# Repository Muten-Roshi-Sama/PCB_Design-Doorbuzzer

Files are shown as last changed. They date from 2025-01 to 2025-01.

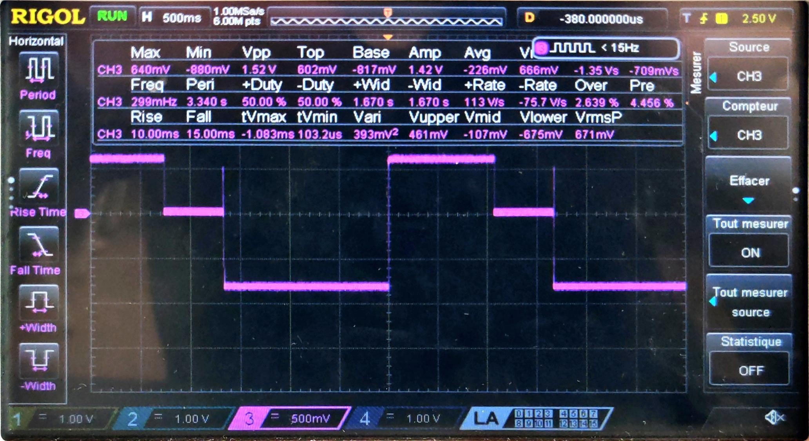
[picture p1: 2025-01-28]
ReportImages/NPN_exp.jpeg

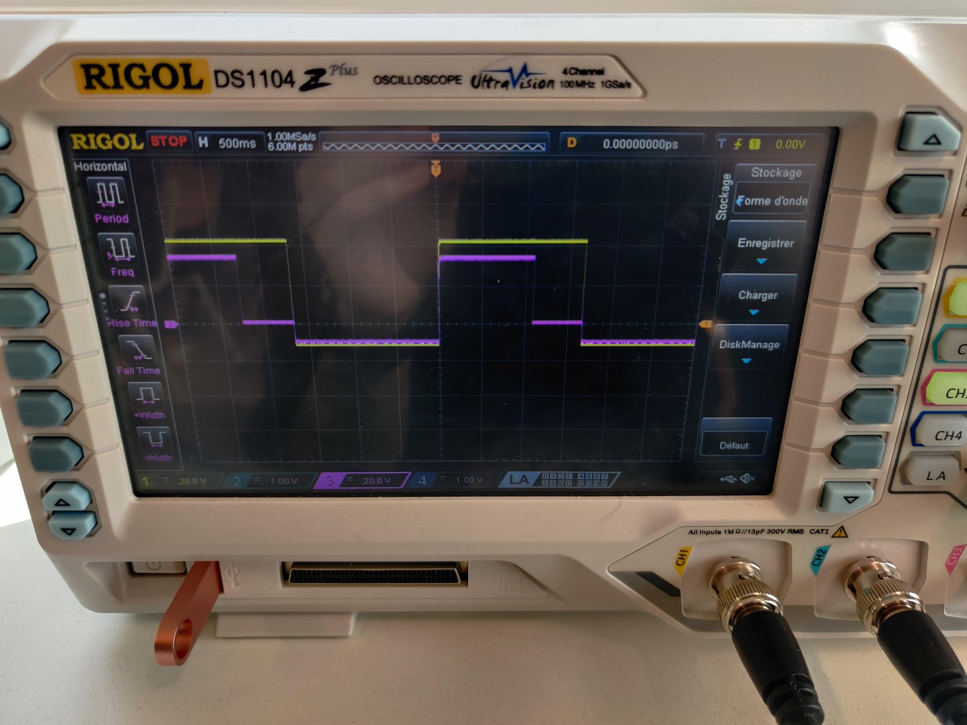
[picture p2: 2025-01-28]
ReportImages/NE555_mono_exp.jpeg

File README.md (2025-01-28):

# PCB_Design-Doorbuzzer
This Circuit¹ is an electronic device designed to produce a two-tone sound, resembling a doorbell, generated through a series of oscillations and feedback loop. Using various components, including LM380N audio power amplifiers, loudspeakers, 555 IC's, and several resistors and capacitors.

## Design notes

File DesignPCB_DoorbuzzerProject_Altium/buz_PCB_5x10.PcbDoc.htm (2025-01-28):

Reporting Options

# File in Previous Format

Date | : | 12/22/2023
Time | : | 1:44:12 PM
Filename | : | C:\Users\vassi\OneDrive\Bureau\Cours\BA3\PCB_design\PCB\Altiummmm\Doorbuzzer\buz_PCB_5x10.PcbDoc

Version | Warning
6.3 | CAUTION - Via connections to both hatched and solid signal layer polygons are now controlled by the polygon connect style rule. Re-pouring polygons may result in physical copper differences.
Summer 09 | CAUTION - File contains old violation objects. These violations are no longer supported & will not be loaded. Please run DRC after opening this file in order to refresh the violations.
Summer 09 | CAUTION - Existing testpoint rules and settings are used as fabrication testpoint information.
Release 12 | CAUTION - Air Gap Width previously controlled by Clearance rule is now controlled by Polygon Connect Style rule's newly introduced Air Gap Width (set to default value). Suggest reviewing each Polygon Connect Style rule's Air Gap Width attribute for correctness.
Release 13 | CAUTION - Silkscreen Over Component Pads Rules are converted to Silk To Solder Mask Clearance Rules. Suggest examining rule scopes for accuracy.

This file was generated by an earlier version of the software

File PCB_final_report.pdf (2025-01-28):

Flioris Vassily
21245

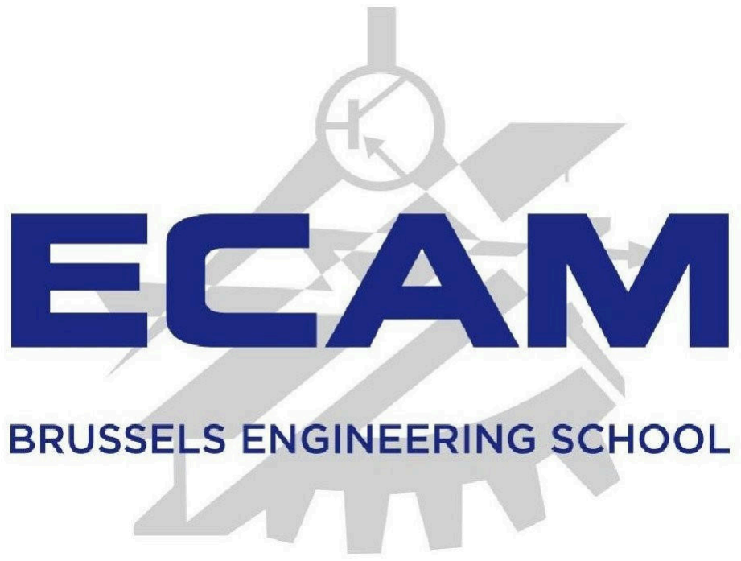
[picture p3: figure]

Ecole Centrale d'Arts et Métiers

# PCB Design Report : Door Buzzer

## Contents

## 1 Introduction

### 1.1 Main functionality of the circuit

The Door Buzzer Circuit¹ is an electronic device designed to produce a two-tone sound, resembling a traditional doorbell. This circuit comprises various components, including an LM380N audio power amplifier, a loudspeaker,

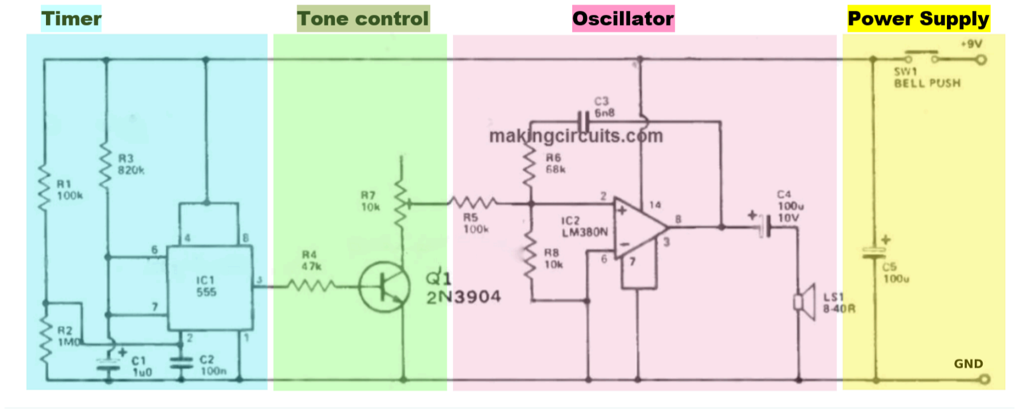
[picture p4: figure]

¹https://makingcircuits.com/blog/door-buzzer-circuit/ an 555 IC, and several resistors and capacitors. The two-tone sound is generated through a series of oscillations and feedback loop.

## 2 Circuit Analysis and Block Diagrams

Figure 1: Door Buzzer schematic.

### 2.1 Expected Behavior on Power-Up

The NE555 timer, configured in monostable mode (a one-shot pulse generator) is activated at Power-Up, generating a one-second pulse on its Output (Pin 3), which in turn activates the NPN transistor Q1.
Concurrently, once the bell button is pressed, the audio amplifier is powered and starts to generate an oscillating output through its feedback loop.
The NPN transistor is activated for one second, during which the tone pitch of the oscillator gets higher (the NPN, then active, concurrently adds R5

and R7

to the circuit, effectively raising the frequency of the tone). After this one-second interval, the NPN deactivates (removing R5

and R7

from the circuit) and the oscillator part of the circuit reverts to its original lower-tone pitch.
This behavior ensures that when the doorbell button is pressed, the circuit produces a distinct higher tone for one second, followed by a lower-tone pitch, producing a ding-dong sound.
Pitch Frequencies relative to the Potentiometer :
- For the first pitch, assuming that :

Req = R6 + (R5 + R7

)// R8
We’d obtain a frequency f1

of about 305.3Hz to 303.62Hz²³

²frequency with and without the potentiometer R7 = 100kΩ. ³using my actual components values.

- Once the timer pulse ends, Q1 turns off. R5 and R7

are no longer in the circuit, and the oscillator returns to its lower frequency :

f2 =

1
2π∗RC =

1
2π∗78k∗6n8 = 301.8 Hz

The frequency difference between f1

and f2

is not great but still noticeable. Refer to the Section 2.5 for discussions on improvements.

Notes :
- Since the monostable mode of the NE555 needs a rising edge to trigger, holding the doorbell (constant High) will not continuously keep the bell ringing. It will only trigger once for the determined duration for each button press (if the presses are sufficiently appart from each other).
- C4
is a Decoupling capacitor (DC-stopping) which blocks the DC component and allows only the AC signal to get to the speaker.
- C5
stabilizes the power supply voltage. The circuit awaits 9V of Vcc.

### 2.2 Timer : NE555

### 2.2.1 Monostable Mode: Design choices and Computations

The NE555 is in Monostable multivibrator mode (one-shot pulse generator) thus will only be triggered once upon pressed. Its datasheet[2] p.10 gives us the following equation for its output Pulse duration :

tw = 1.1 ∗ RA ∗ C
using Ra = 820k and C = 1 µF, one obtains :

tw = 0.902s
We verify this computation by simulation (see Figure 2) and by experimentation (see Figure 4). Explanations of those results are included in Section 2.5.

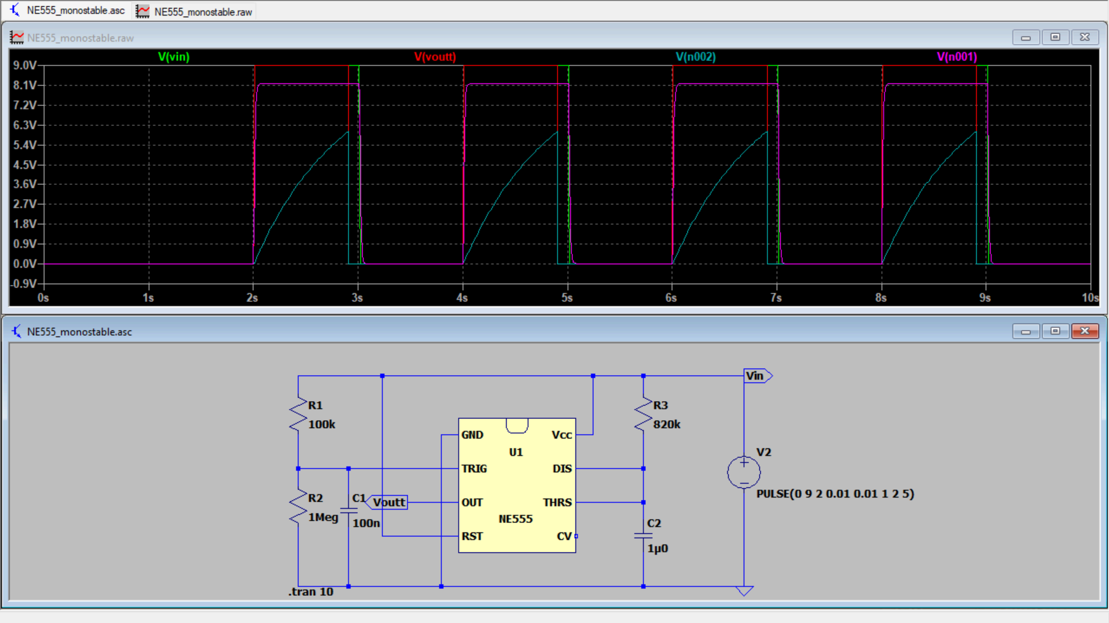
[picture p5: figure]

Figure 2: Monostable simulation of the NE555. In monostable mode, the NE555 timer is configured to produce an output pulse of a fixed duration. Upon pressing the button, the trigger input (Vtrig) goes low briefly (i.e. falls below 1/3 Vcc) and the TRIG comparator (see Figure 3) Sets the flipflop, making its output high and turns off the discharge transistor allowing C1

(or C2

in
the simulated circuit, Figure 2) to charge through R3

until the threshold voltage reaches 2/3 Vcc. Recall that this will take 1.1RC seconds (or approximately 0.9 seconds in our simulation Figure 2, which is consistent with the pulse duration we previously calculated).
When it gets to that point (i.e. the capacitor voltage V(n002) reaches 2/3 Vcc, here 6V), the THRES comparator Resets the flipflop, making the output low, and turns on the discharge transistor which grounds the discharge pin. Since this is connected directly to the point between the capacitor and resistor, the capacitor discharges essentially instantaneously. This also causes the threshold voltage to go to zero, and the flipflop’s Reset input to go low. Now both the Set and Reset inputs to the flipflop are low and the circuit is again in a stable state with the output low. [4]

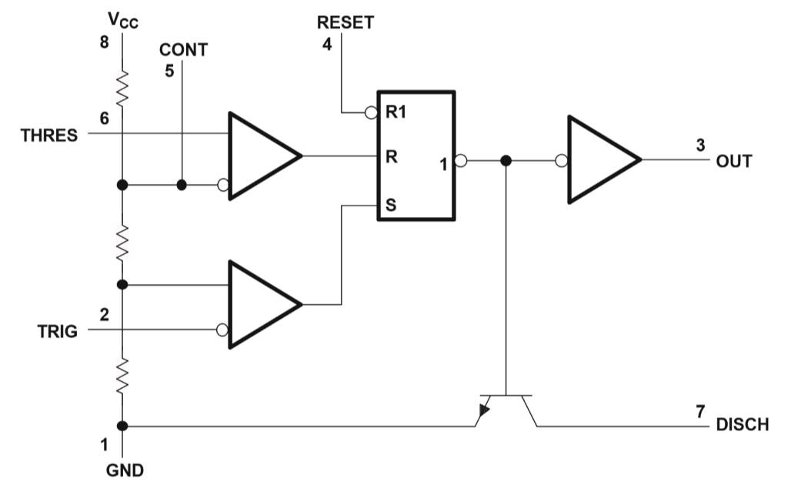
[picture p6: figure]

Figure 3: NE555 Functional Block Diagram.

### 2.2.2 Experimental Verification of the NE555 Timer’s Pulse Generation Capabilities

To verify the pulse generation capabilities of the NE555 timer, we conducted an experiment using a signal generator with a pulse at 400mHz imitating a bell push. The resulting output pulse of the NE555 is 1.2 seconds, slightly deviating from our calculated value of 0.9 seconds. Possible reasons for this may include:

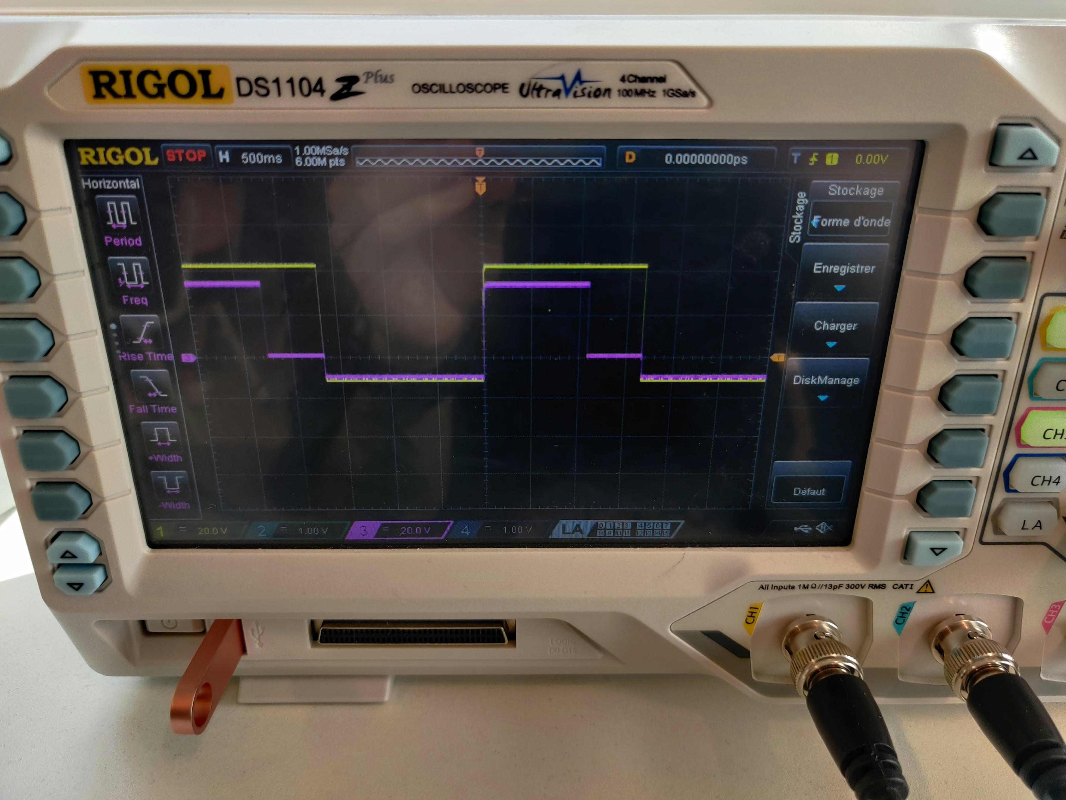
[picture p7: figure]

Figure 4: Monostable experimentation of the NE555.
1. Component tolerance: The actual resistance and capacitance may differ from their nominal values. Which could result in a longer output pulse duration. Which can be easily solved by manually checking them.
2. Triggering mechanism: The NE555 might be triggered again before the output pulse has fully decayed, resulting in a longer overall pulse duration. This can be solved by adding a debounce mechanism on the button, but the signal generator used for this experiment, voids any possible bouncing of the signal.
3. Leakage Current: Small leakage currents within the NE555 timer itself or on the PCB can cause the capacitor to discharge slowly, extending the pulse duration.
4. Stray Capacitance: Parasitic capacitance from wiring or components close together can add to the overall capacitance.

### 2.3 Tone Control : NPN Transistor 2N3904

### 2.3.1 Collector-Impedance Frequency response

The NPN transistor is used to switch resistances in and out of the circuit, which changes the value of the time constant and thus the frequency of the oscillations. Starting from the collector of the NPN, we compute its Impedance as following :
Zeq = R7 + R5 + (R6 +
1
sC3

) // R8

Zeq = R7 + R5 + (R8 ∗
R6+

1
sC3
R8+R6+

1
sC3

)

Zeq = R7 + R5 + (
sC3∗R6∗R8+R8
sC3

(R8+R6

)+1

) =
(R7+R5

)∗[sC3

(R8+R6

)+1]+sC3R8R6+R8
sC3

(R8+R6

)+1
with s = jω = j ∗ 2πf :

Zeq =

(R7+R5+R8

)+jω[(R7+R5

)(R6+R8

)∗C3+R8R6C3

]
1+jω[C3

(R6+R8

)]
Plugging the numerator and denominator in the Pythagorean formula :

|Z| =

√(R7+R5+R8
)

2+(((R7+R5
)(R6+R8

)C3+R8R6C3

)2πf)

2

√1+((R6+R8
)C32πf)

2
This last expression and its graph Figure 5 represents the magnitude of the complex impedance as seen by the output of the amplifier looking into the rest of the circuit. This would be the magnitude part of a Bode plot. At frequencies above 1kHz the output impedance is around 110k.

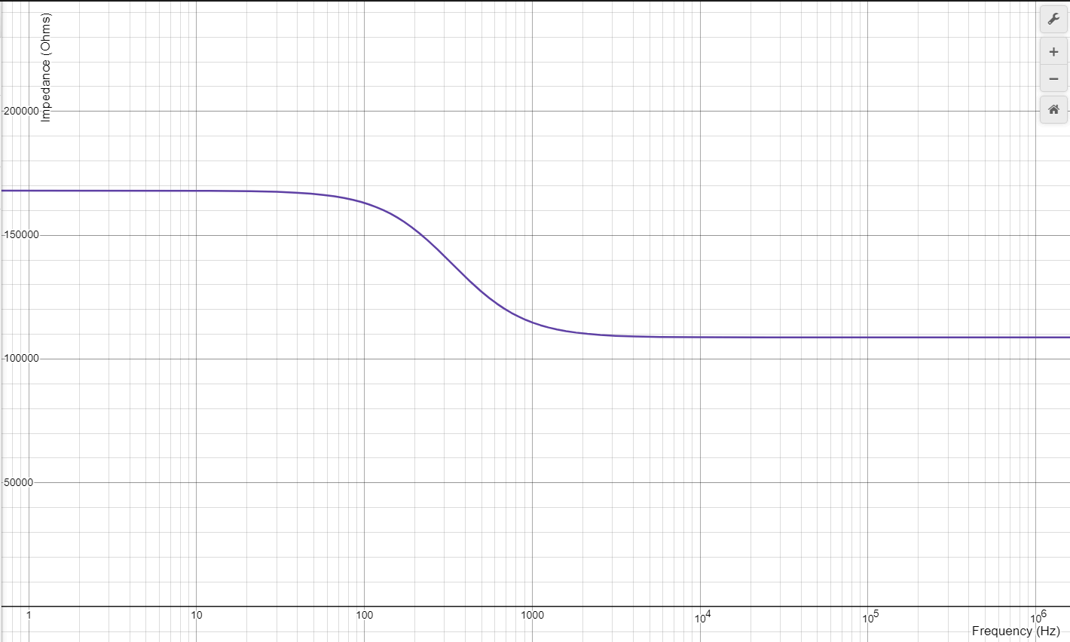
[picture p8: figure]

Figure 5: Impedance-Frequency Bode plot. We are now able to compute the Collector current :

IC =

Vcc
Zeq

=

9V
110k = 75 to 82μA (with and without R7 )
To ensure to be in saturation down to a Vc of about 1V, we choose hFe = 0.45 for Ic < 0.1mA (which is the lowest possible value from Figure 15 called “Dc Current Gain” from 2N3904′s datasheet [3]) :

IB =

IC
hFe = 160 to 180μA
and finally :

Rbase =

Vcc−VBE
IB

= 46 to 50kΩ
The closest E12 value would be 47k.

### 2.3.2 Experimental verification of the Pulse Duration

Measuring the voltage experimentally at the NPN gate, we observe it being open for the duration of the output pulse generated by the NE555, reaching 640mV (see Figure 6) as seen in the NPN-datasheet[3] (VBE = 0.65V ). Why the transistor is conducting below the built-in voltage (0.65V) might be because of carrier injection from a Shockley boundry condition[9].
When testing the limits of this circuit, increasing the Voltage source above 9V resulted in a VBE up to 0.75V.

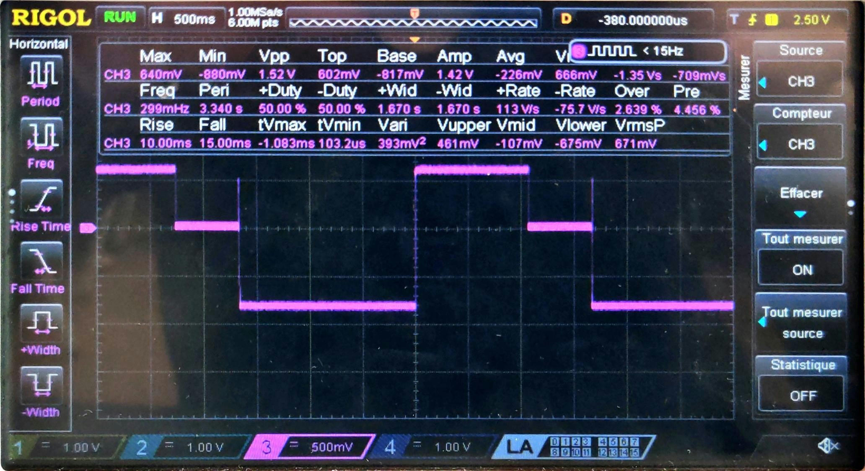
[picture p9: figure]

Figure 6: Voltage VBE of the transitor.

### 2.4 Oscillator : LM380N audio power amplifier

Audio amplifiers, compared to general purposes Op-Amps, are optimized for minimizing distortion and preserving audio quality, for instance we can find out that the LM380 [6] :
- Vs power supply 10V - 22V
- General uses include : simple phonograph amplifiers, intercoms, line drivers, alarms, ultrasonic drivers, TV sound systems, AM-FM radio, small servo drivers, power converters, etc.
- Bandwidth up to 100kHz.
The audio amplifier seems to be in a sort of Schmitt Trigger installation with the main difference being the position of the capacitance (inside the feedback loop in our circuit compared to outside in a more classic Scmitt Trigger circuit, see Figure 7).

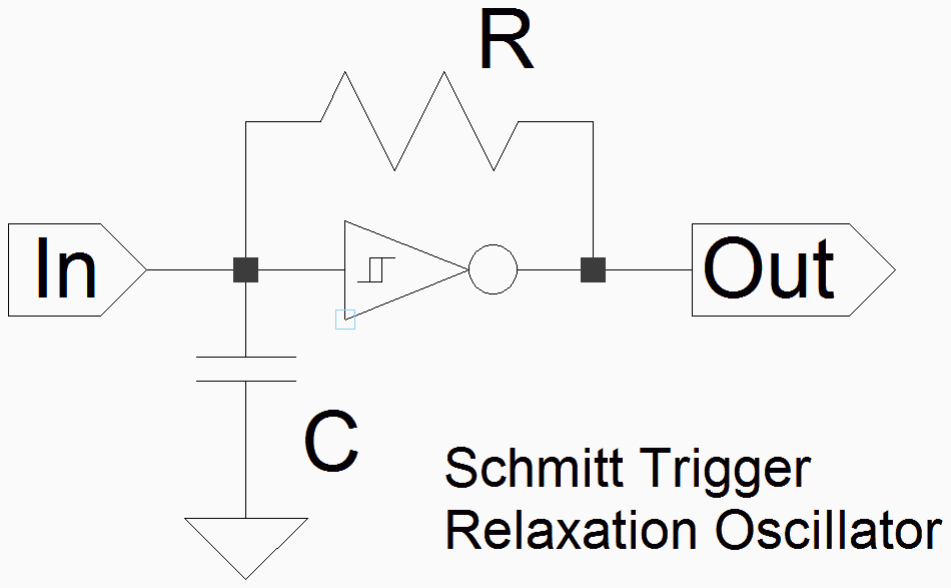
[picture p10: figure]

Figure 7: source : [7]
So where does the oscillations originates from ?
Some internal parasitic oscillations (due to Johnson’s thermal noise⁴⁵) start to affect the voltage on the feedback capacitor. This creates a small voltage difference between the inputs of the Opamp, which will be gradually am-

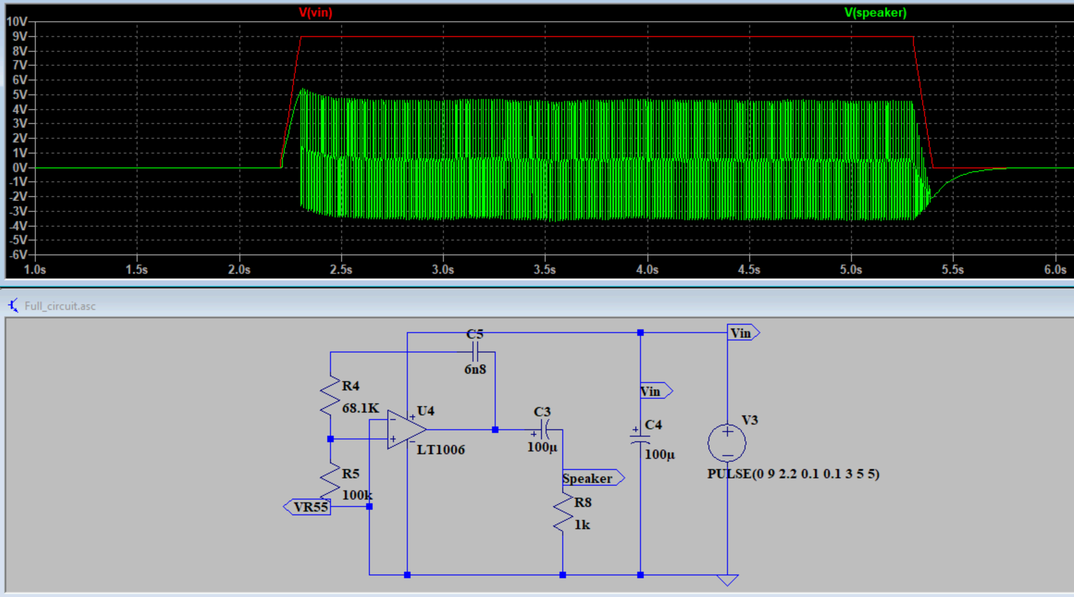
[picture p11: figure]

⁴J. B. Johnson (1928) “Thermal Agitation of Electricity in Conductors, Phys. Rev. 32, 97 “ https://journals.aps.org/pr/abstract/10.1103/PhysRev.32.97 (https://journals.aps.org/pr/abstract/10.1103/PhysRev.32.97)
⁵Texas Instrument “Op Amp Noise Theory and Applications” https://intranet.ee.ic.ac.uk/t.clarke/ee2lab/handouts/A/noise-3.pdf (https://intranet.ee.ic.ac.uk/t.clarke/ee2lab/handouts/A/noise-3.pdf)

plified over and over again. This then taking as long as necessary to amplify until fully charging and discharging the capacitor C3

leading to the full amplitude of the oscillations. We should also take into account that the speaker connected to the op-amp’s output acts as a non-linear load, it’s vibration changes the resistance of the circuit, thus also affecting the feedback voltage.

### 2.4.1 Simulation Analysis of the LM380N Audio Amplifier

Since no model for the LM380N audio amplifier was found online, I simulated my circuit using another amplifier : the LT1006 Op-Amp [5].
Here we obtain a stable oscillation of about 77.5Hz, we do not expect this value to be representative for our circuit since the resistors value were adapted for the the 2.5million gain of the LT1006 Op-Amp. We would expect, however, that our LM380N audio amplifier would oscillate with more precision.

Figure 8: LT1006 amplifier oscillator.

### 2.5 Personal Contributions :

### 2.5.1 Changing the notes frequency

When designing a doorbell circuit, achieving a traditional “ding-dong” sound comprising of two distinct notes
- Mi and Do - is crucial. According to [8], this classic sound is typically comprised of these two notes. The corresponding frequencies for these notes are:
- C (Do) : 261.63 Hz
- E (Mi) : 329.63 Hz
which we rounded to the nearest integer.
To produce these specific notes, a formula can be used to calculate the equivalent resistance:

Req =

1
2πfC
When the circuit is activated, it initially emits a “Mi” pitch (NPN activated, see green path Figure 9). One second later, the second note, “Do”, is emitted (see orange path).
To adjust the pitch, I picked R7

to be at 50kΩ for manual fine-tuning (R7 = 0k − 100kΩ). Using these values for R6
, R5

, and R8

:

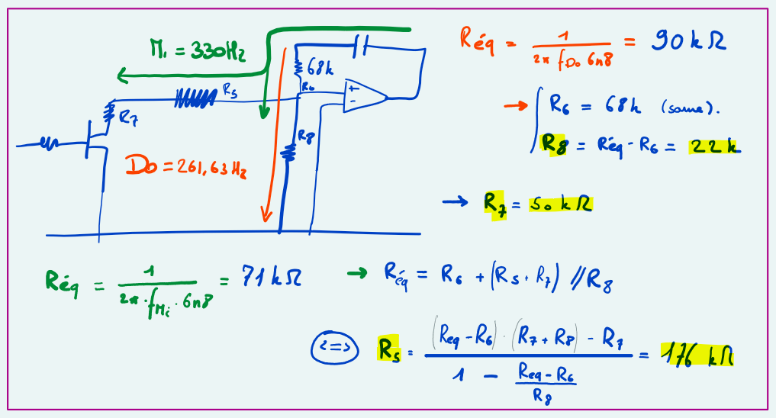
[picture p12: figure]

Figure 9: Computations to achieve a classic “ding-dong” sound on the circuit.

### 2.5.2 Components

In the case I’d re-design my circuit I would :
1. Add a protection diode: The circuit doesn’t have any protection against voltage surges or spikes. Especially if we plan to power it using a house outlet.
2. Using a more modern transistor: The 2N3904 transistor is a bit old, we could use a transistor with better characteristics, such as the BC547 or BC557.
3. Changing the Bell push : we could choose another mechanism that makes sure the power is High for at least 2 seconds (1sec for each note).

### 2.5.3 Alarm Detector using the Astable Mode

For my final circuit, I opted for an Astable mode instead of a monostable mode. The two-tone buzzer achieved using the monostable mode was not audible enough and didn’t really sound like a doorbell.
The Astable mode allows for a continuous ringing sound (dring-dring) as long as the button is pressed. Now instead of a one-shot pulse, the ne555 will output an oscillating signal to the NPN, changing the tone following the Astable frequency.

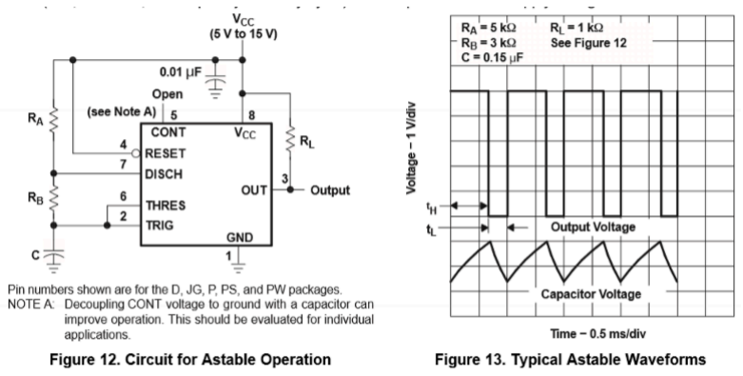
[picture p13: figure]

Figure 10: Astable Configuration [2]. Using
- Ra = 100k,
- Rb = 1M0 and,
- C = 100 nF
we obtain a switching frequency [2] of f =

1.44
(Ra+2Rb

)∗C = 6.85 Hz
To go further, the Astable configuration for this circuit allows it to be adapted as an “Alarm detector”. Inverting the bell button, the alarm will ring whenever a door in your house has been opened after placing the electrodes of contact to the door/wall which opens the circuit.

### 3 Sources and references (following APA norms) :

[1] : AspenCore (2024) “555 Timer Tutorial” consulted the 14/04/2024 on : https://www.electronics-tutorials.ws/waveforms/555_timer.html (https://www.electronics-tutorials.ws/waveforms/555_timer.html)
[2] : Texas Instruments (2024) “xx555 Precision Timers datasheet “ consulted the 14/03/2024 on : https://www.ti.com/product/NE555 (https://www.ti.com/product/NE555)
[3] : ONSEMI [ON Semiconductor] (2024) “2N3903 Datasheet (PDF) - ON Semiconductor” consulted the 14/04/2024 on : https://www.alldatasheet.com/datasheet-pdf/pdf/11469/ONSEMI/2N3903.html
[4] : Dave Astel (2024) “Getting to know the 555 : Monostable Operation” consulted the 15/04/2024 on : https://learn.adafruit.com/getting-to-know-the-555/monostable (https://learn.adafruit.com/getting-to-know-the-555/monostable)
[5] : Texas Instruments (2024) “LT1006 Datasheet by Analog Devices Inc.” consulted the 20/04/2024 on : https://www.digikey.com/en/htmldatasheets/production/80162/0/0/1/lt1006
[6] : Digikey “ LM380 2.5W Audio Power Amplifier datasheet (Rev. C)” consulted the 20/04/2024 on : https://www.ti.com/product/LM380 (https://www.ti.com/product/LM380)
[7] : Wikipedia (2024) “Schmitt trigger” consulted the 20/04/2024 on : https://en.wikipedia.org/wiki/Schmitt_trigger
[8] : Wiki user (2022) “What is the frequency of Do-Re-Mi?” consulted the 14/04/2024 on : https://qa.answers.com/musicand-radio/What_is_the_frequency_of_Do-Re-Mi (https://qa.answers.com/music-and-radio/What_is_the_frequency_of_Do-Re-Mi)
[9] CHU-Berkeley (2009) : PN and Metal–Semiconductor Junctions : https://www.chu.berkeley.edu/wp-content/uploads/2020/01/Chenming-Hu_ch4-1.pdf#page=17 (https://www.chu.berkeley.edu/wp-content/uploads/2020/01/Chenming-Hu_ch4-1.pdf#page=17)

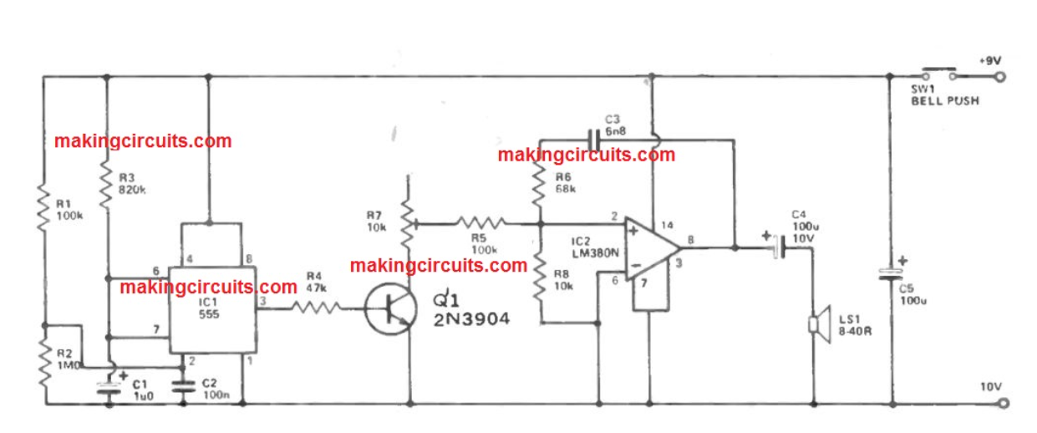
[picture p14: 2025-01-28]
ReportImages/DB_circuit.png

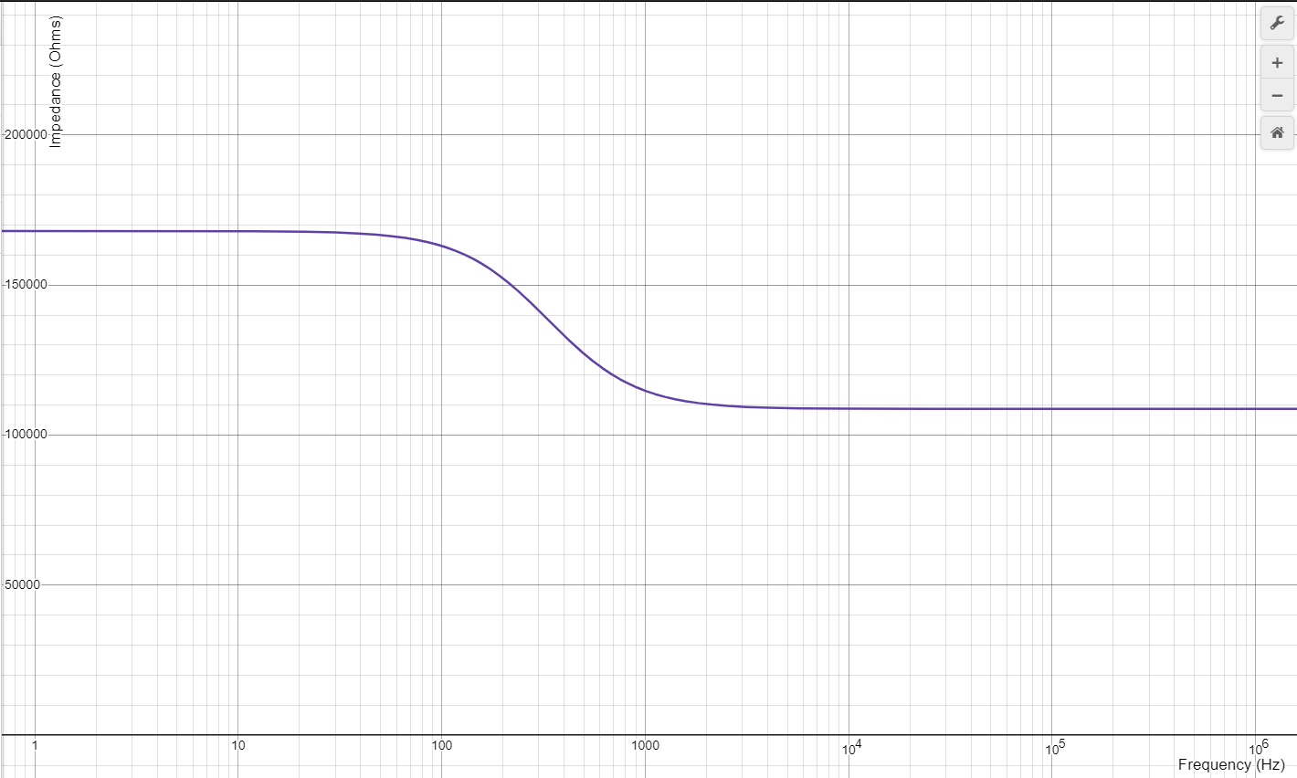
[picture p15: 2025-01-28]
ReportImages/impedPlot.png

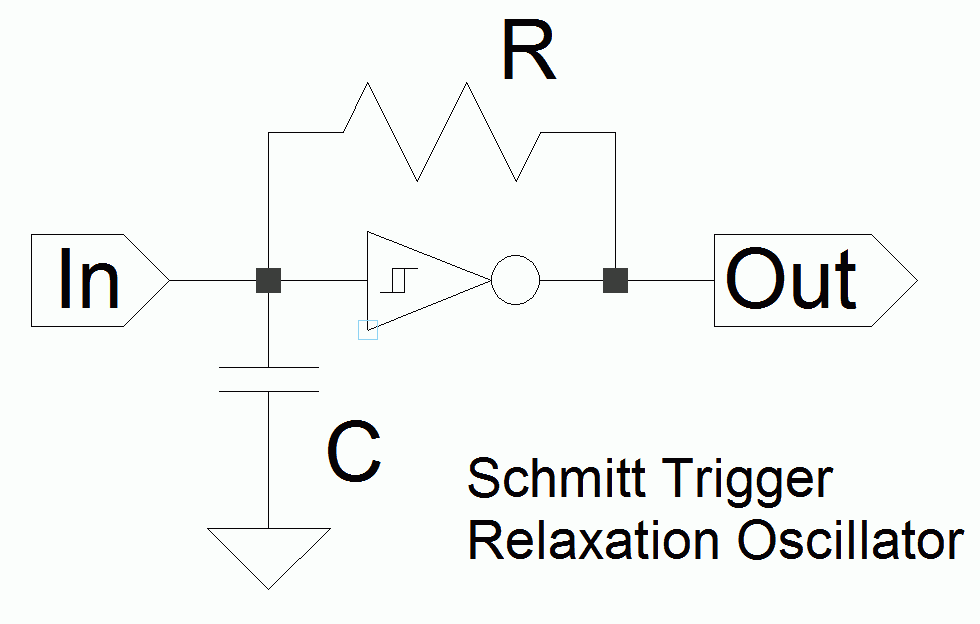
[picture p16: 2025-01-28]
ReportImages/SchmittTriggerRelaxationOscillator.png

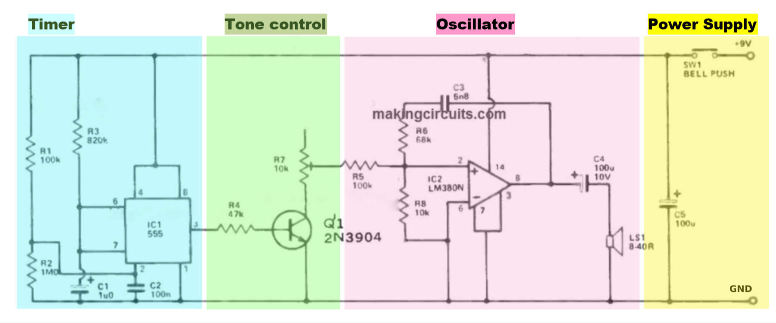
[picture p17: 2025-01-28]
ReportImages/circuits_color.png

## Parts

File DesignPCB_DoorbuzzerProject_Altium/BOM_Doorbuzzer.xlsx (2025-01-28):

Comment | Description | Designator | Footprint | LibRef | Quantity
1u0 | Polarized Capacitor (Radial) | C1 | RB7.6-15 | Cap Pol1 | 1
Cap | Capacitor | C2 | RAD-0.3 | Cap | 1
6n8 | Capacitor | C3 | RAD-0.3 | Cap | 1
100u | Polarized Capacitor (Radial) | C4, C5 | RB7.6-15 | Cap Pol1 | 2
8-40R | Loudspeaker | LS1 | AXIAL-0.4 | Speaker | 1
2N3904BU | NPN General-Purpose Amplifier, 40 V VCEO, 0.2 A, -55 to 150 degC, 2-Pin TO-92, RoHS, Bulk | Q1 | FAIR-TO-92 | 2N3904BU | 1
Res2 | Resistor | R1, R2, R3, R4, R5, R6, R7, R8 | AXIAL-0.4 | Res2 | 8
NE555DR | IC OSC SGL TIMER 100KHZ 8-SOIC | U1 | FP-D0008A-IPC_C | 555 | 1
LM380N | 2.5W Audio Power Amplifier, 14-pin MDIP | U2 | N14A | LM380N | 1
